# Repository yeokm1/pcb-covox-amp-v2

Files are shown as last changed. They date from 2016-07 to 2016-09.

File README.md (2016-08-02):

# pcb-covox-amp-v2
A tiny sound card based on the Covox Speech Thing design which includes an LM386 amplifier and FT245RL chip to receive data via USB. This project is a combination of my 2 earlier projects [pcb-covox-amp](https://github.com/yeokm1/pcb-covox-amp) and [pcb-usb-ft245r-parallel-adapter](https://github.com/yeokm1/pcb-usb-ft245r-parallel-adapter)

##PCB Design software and addons used

1. Kicad 4.0.2 or later

##Images
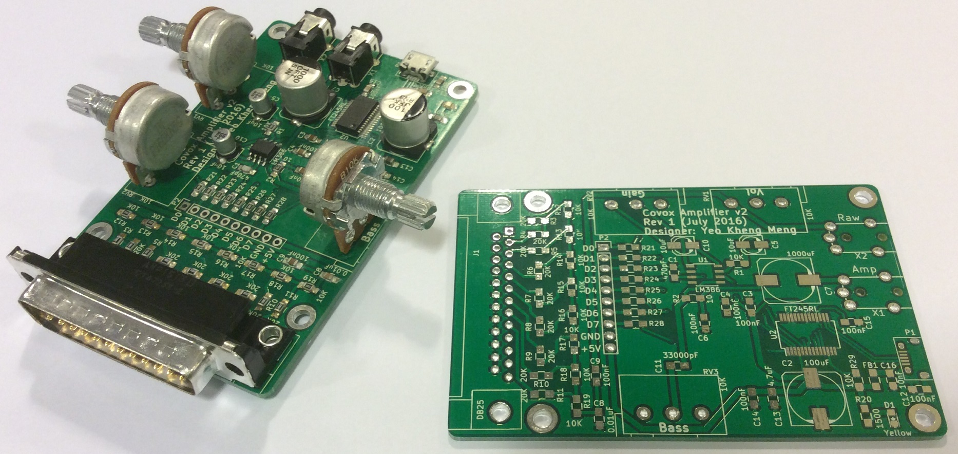
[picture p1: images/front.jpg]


##Schematic drawings

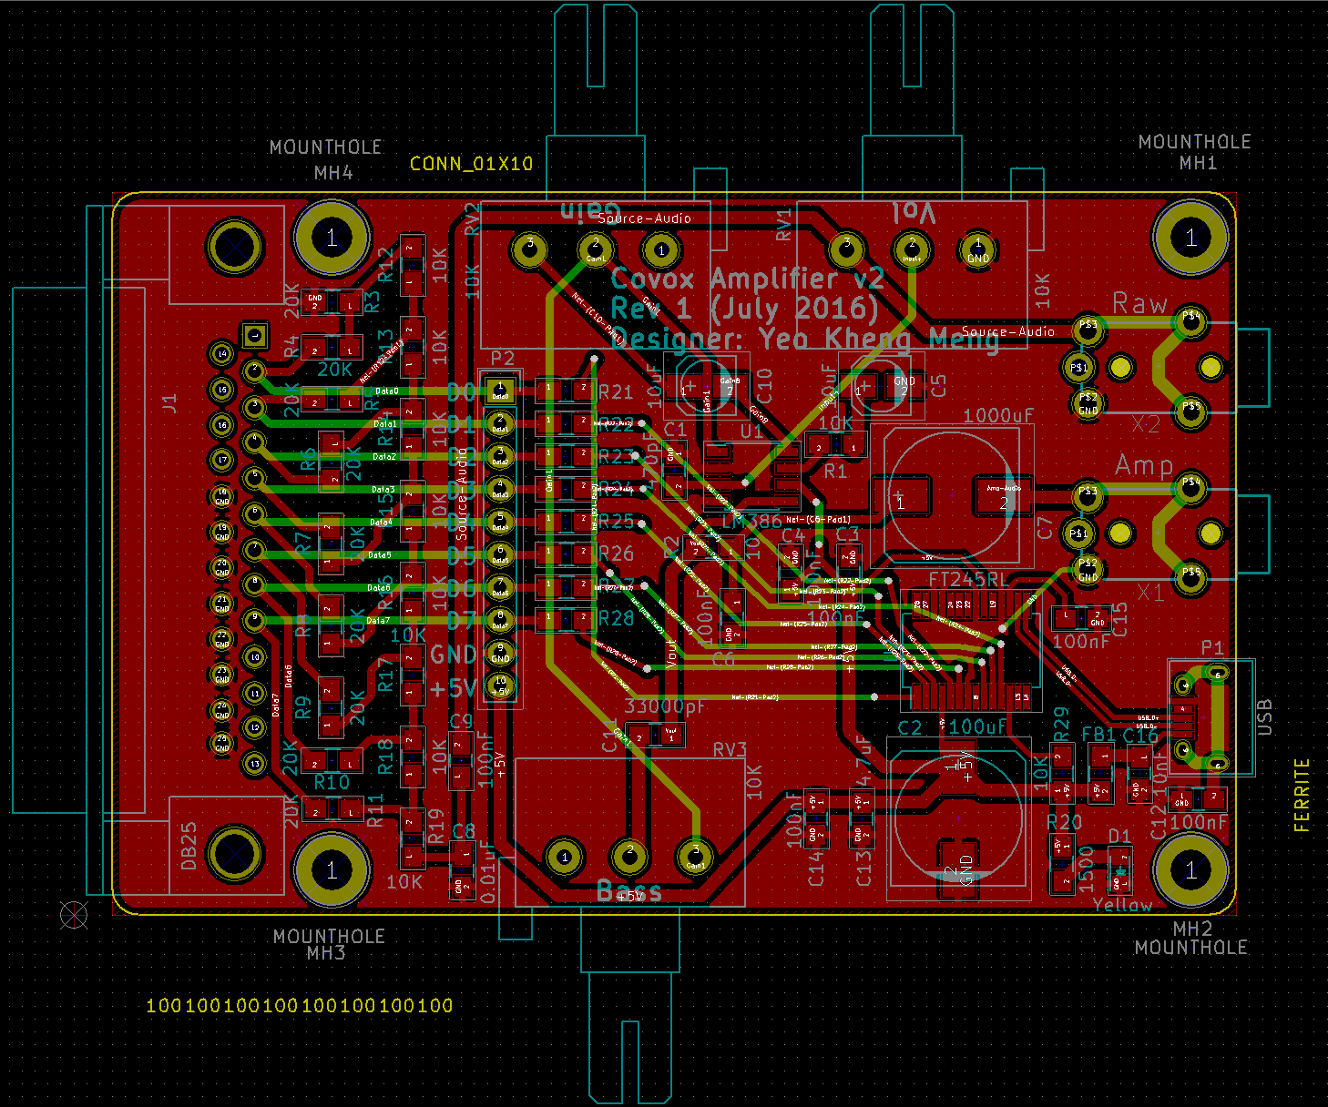
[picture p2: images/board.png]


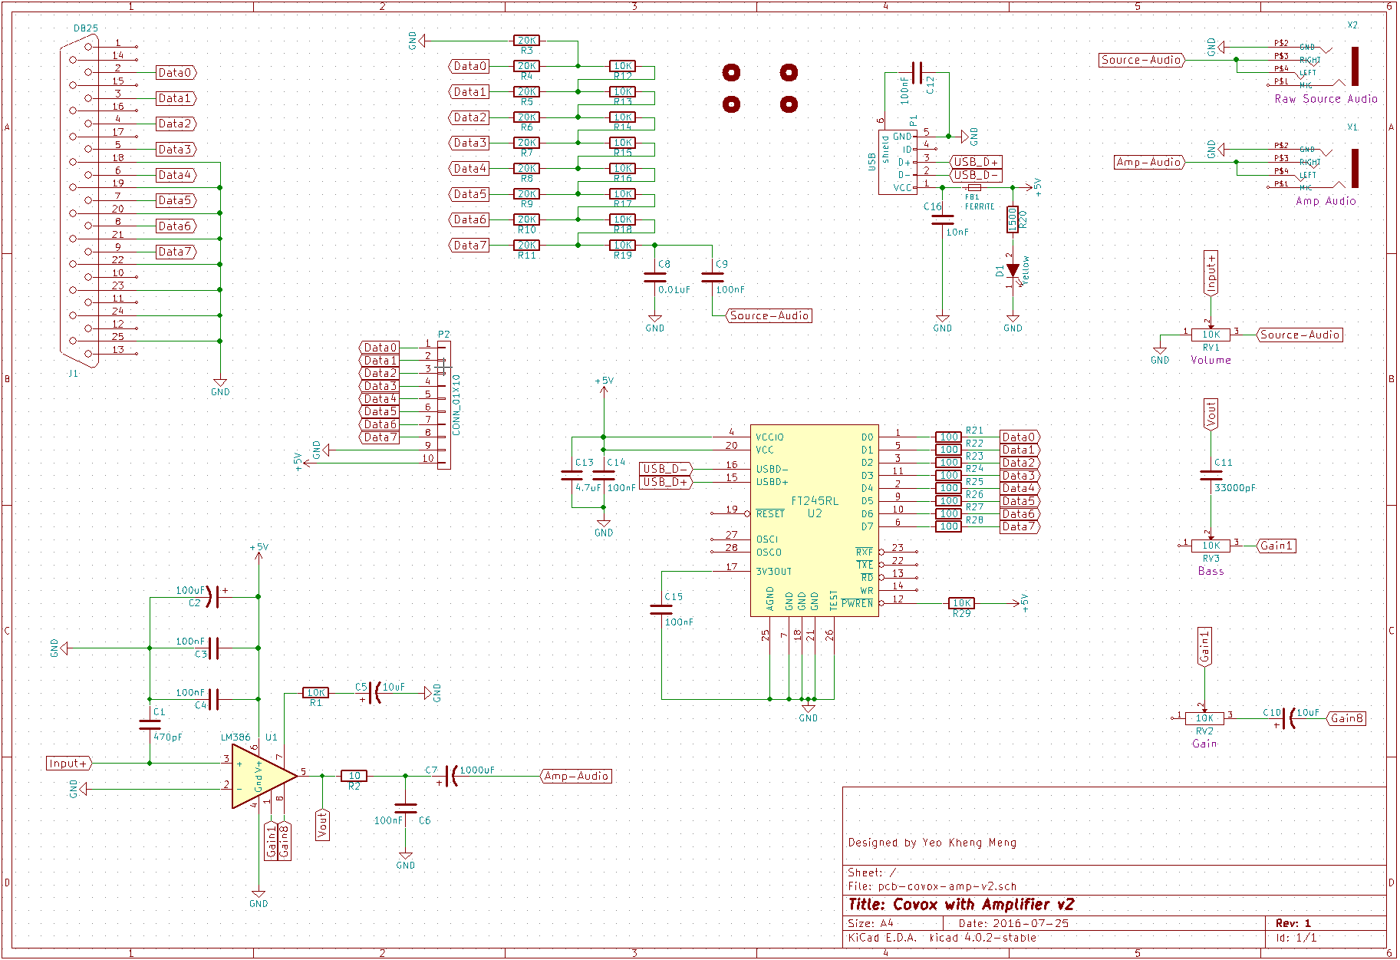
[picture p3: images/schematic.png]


##Parts required
Use Libreoffice to open [pcb-covox-amp-v2-bom.ods](pcb-covox-amp-v2-bom.ods)

##References
1. [Hardware implementation references](https://blog.frantovo.cz/c/307/DAC%20%28zvukov%C3%A1%20karta%29%20pro%20LPT%20port%20a.k.a.%20Covox)
2. [Design reference](http://kb.gr8bit.ru/KB0010/GR8BIT-KB0010-Adding-multimedia-capability-covox-device.html)
3. [MJ-2135 package referenced from coqui-dip](https://github.com/open-eie/coqui-dip)
4. [Amplifier circuit](http://www.circuitbasics.com/build-a-great-sounding-audio-amplifier-with-bass-boost-from-the-lm386/)

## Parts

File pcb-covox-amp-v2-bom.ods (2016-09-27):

Designator | Device | Package | Value | Manufacturer | Part Number | Quantity | Unit Cost | Total Unit Cost | Source webpage
U2 | FTDI FT245RL Interface Bridges, USB to FIFO, 1.8 V, 5.25 V, SSOP, 28 Pins, -40 °C | SSOP28, 5.3mm x 10.2mm | FT245RL | FTDI | FT245RL | 1 | 5.96 | 5.96 | http://sg.element14.com/ftdi/ft245rl/interface-usb-to-fifo-28ssop/dp/1146034
J1 | Standard D Sub Connector, AMPLIMITE HD-20 Series, DB, Plug, 25 Contacts, Steel Body, Through Hole | DB25MC | DB25 | TE Connectivity/ AMP | 5747238-2 | 1 | 5.15 | 5.15 | http://sg.element14.com/te-connectivity-amp/5747238-2/d-sub-connector-plug-25pos/dp/2452364
C1 | SMD Multilayer Ceramic Capacitor | C_0805_HandSoldering | 470pF | AVX | 08055A471JAT2A | 1 | 0.162 | 0.162 | http://sg.element14.com/avx/08055a471jat2a/cap-mlcc-c0g-np0-470pf-50v-0805/dp/1612188
C2 | SMD Aluminium Electrolytic Capacitor, AEC-Q200 FT Series | c_elec_10x10.5 | 100uF, 63V | Panasonic Electronic Components | EEEFK1J101P | 1 | 1.49 | 1.49 | http://sg.element14.com/panasonic-electronic-components/eeefk1j101p/cap-alu-elec-100uf-63v-smd/dp/9696040
C3,C4,C6,C9,C12,C14,C15 | SMD Multilayer Ceramic Capacitor, MCU Series | C_0805_HandSoldering | 100nF | Multicomp | MCU0805F104ZCT | 7 | 0.008 | 0.056 | http://sg.element14.com/multicomp/mcu0805f104zct/cap-mlcc-y5v-100nf-50v-0805/dp/9406409RL
C7 | SMD Aluminium Electrolytic Capacitor, AEC-Q200 FT Series | c_elec_10x10.5 | 1000uF, 16V | Panasonic Electronic Components | EEEFT1C102AP | 1 | 1.47 | 1.47 | http://sg.element14.com/panasonic-electronic-components/eeeft1c102ap/cap-alu-elec-1000uf-16v-smd/dp/2065974
C8 | SMD Multilayer Ceramic Capacitor | C_0805_HandSoldering | 0.01uF | AVX | 08055C103KAT2A | 1 | 0.049 | 0.049 | http://sg.element14.com/avx/08055c103kat2a/cap-mlcc-x7r-10nf-50v-0805/dp/499225
C11 | SMD Multilayer Ceramic Capacitor | C_0805_HandSoldering | 33000pF | AVX | 08051C333KAT2A | 1 | 0.076 | 0.076 | http://sg.element14.com/avx/08051c333kat2a/cap-mlcc-x7r-33nf-100v-0805/dp/1833886
P1 | USB Connector, Micro USB Type B, USB 2.0, Receptacle, 5 Ways, Surface Mount, Through Hole Mount | USB_Micro-B | Micro-USB | Hirose | ZX62D-B-5PA8(30) | 1 | 1.09 | 1.09 | http://sg.element14.com/webapp/wcs/stores/servlet/ProductDisplay?productId=141569308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
R1,R12,R13,R14,R15,R16,R17,R18,R19,R29 | Surface Mount Chip Resistor, Thick Film, AEC-Q200 ERJ6E Series | R_0805_HandSoldering | 10K, ±0.5% | Panasonic Electronic Components | ERJ6RBD1002V | 10 | 0.047 | 0.47 | http://sg.element14.com/panasonic-electronic-components/erj6rbd1002v/res-thick-film-10k-0-5-0-1w-0805/dp/2380289
R2 | Thick Film Resistor | R_0805_HandSoldering | 10 | Panasonic Electronic Components | ERJ-6ENF10R0V | 1 | 0.156 | 0.156 | http://sg.element14.com/panasonic-electronic-components/erj-6enf10r0v/sistor-thick-film-10-ohm-125mw/dp/2284223
R3,R4,R5,R6,R7,R8,R9,R10,R11 | Surface Mount Chip Resistor, Thick Film, AEC-Q200 ERJ6E Series | R_0805_HandSoldering | 20K, ±0.5% | Panasonic Electronic Components | ERJ6RBD2002V | 9 | 0.047 | 0.423 | http://sg.element14.com/panasonic-electronic-components/erj6rbd2002v/res-thick-film-20k-0-5-0-1w-0805/dp/2380338
RV1,RV2,RV3 | Rotary Potentiometer | Potentiometer_Alps-RK163-single_15mm | 10K | BI Technologies/ TT Electronics | 16mm | 3 | 1.16 | 3.48 | http://sg.element14.com/bi-technologies-tt-electronics/p160kn-0qd15b10k/rotary-potentiometer-10kohm-16mm/dp/1782728
U1 | LM386M-1 Audio Power Amplifier, AB, 1 Channel, 325 mW, 4V to 12V | SOIC8 | LM386 | Texas Instruments | LM386M-1/NOPB | 1 | 1.48 | 1.48 | http://sg.element14.com/texas-instruments/lm386m-1-nopb/amp-power-audio-mono-class-ab/dp/1564701
D1 | LED, Yellow Green, SMD, 1.25mm x 1.4mm, 20 mA, 2 V, 575 nm | LED_0805 | Yellow, Green | Dialight | 5988160107F | 1 | 0.657 | 0.657 | http://sg.element14.com/dialight/5988160107f/led-0805-yellow-green-40mcd/dp/1465994
R20 | Thick Film Resistor | R_0805_HandSoldering | 1500 | Multicomp | MC0805S8F1501T5E | 1 | 0.005 | 0.005 | http://sg.element14.com/multicomp/mc0805s8f1501t5e/res-thick-film-1k5-1-0-125w-0805/dp/1632464
X1, X2 | Phone Audio Connector, Socket, 3.5 mm, 4 Contacts, PCB Mount | mj-2135-MJ-2135 | TRRS | Pro Signal | MJ-2135 | 2 | 3.79 | 7.58 | http://sg.element14.com/pro-signal/mj-2135/connector-rca-jack-3-5mm-tht-4way/dp/1267377
C5,C10 | SMD Aluminium Electrolytic Capacitor, AEC-Q200 FT Series | c_elec_4x5.3 | 10uF, 10V | Panasonic Electronic Components | EEE1AA100NR | 2 | 0.99 | 1.98 | http://sg.element14.com/panasonic-electronic-components/eee1aa100nr/cap-alu-elec-10uf-10v-smd/dp/2326096
C13 | SMD Multilayer Ceramic Capacitor | C_0805_HandSoldering | 4.7uF | Kemet | C0805C475K3PACTU | 1 | 0.469 | 0.469 | http://sg.element14.com/kemet/c0805c475k3pactu/cap-mlcc-x5r-4-7uf-25v-0805/dp/1572631
C16 | SMD Multilayer Ceramic Capacitor | C_0805_HandSoldering | 10nF | AVX | 08055C103KAT2A | 1 | 0.049 | 0.049 | http://sg.element14.com/avx/08055c103kat2a/cap-mlcc-x7r-10nf-50v-0805/dp/499225
FB1 | Ferrite Bead | R_0805_HandSoldering | FERRITE | Laird Technologies | MI0805K400R-10 | 1 | 0.103 | 0.103 | http://sg.element14.com/laird-technologies/mi0805k400r-10/ferrite-bead-2012-100mhz-40r/dp/2292459
R21,R22,R23,R24,R25,R26,R27,R28 | Surface Mount Chip Resistor, Thick Film, AEC-Q200 ERJ6E Series | R_0805_HandSoldering | 100 | Panasonic Electronic Components | ERJ6RBD1000V | 8 | 0.047 | 0.376 | https://sg.element14.com/panasonic-electronic-components/erj6rbd1000v/res-thick-film-100r-0-5-0-1w-0805/dp/2380287
- | PCB (Hasl lead free) | 5x10cm x 2 layer | - | Elecrow | - | 1 | 8 | 8 | http://www.elecrow.com/5pcs-2-layer-pcb-p-1174.html
 |  |  |  |  |  |  | Subtotal | 40.731
 |  |  |  |  |  |  | GST 7% | 2.85117
 |  |  |  |  |  |  | Total (SGD) | 43.58217

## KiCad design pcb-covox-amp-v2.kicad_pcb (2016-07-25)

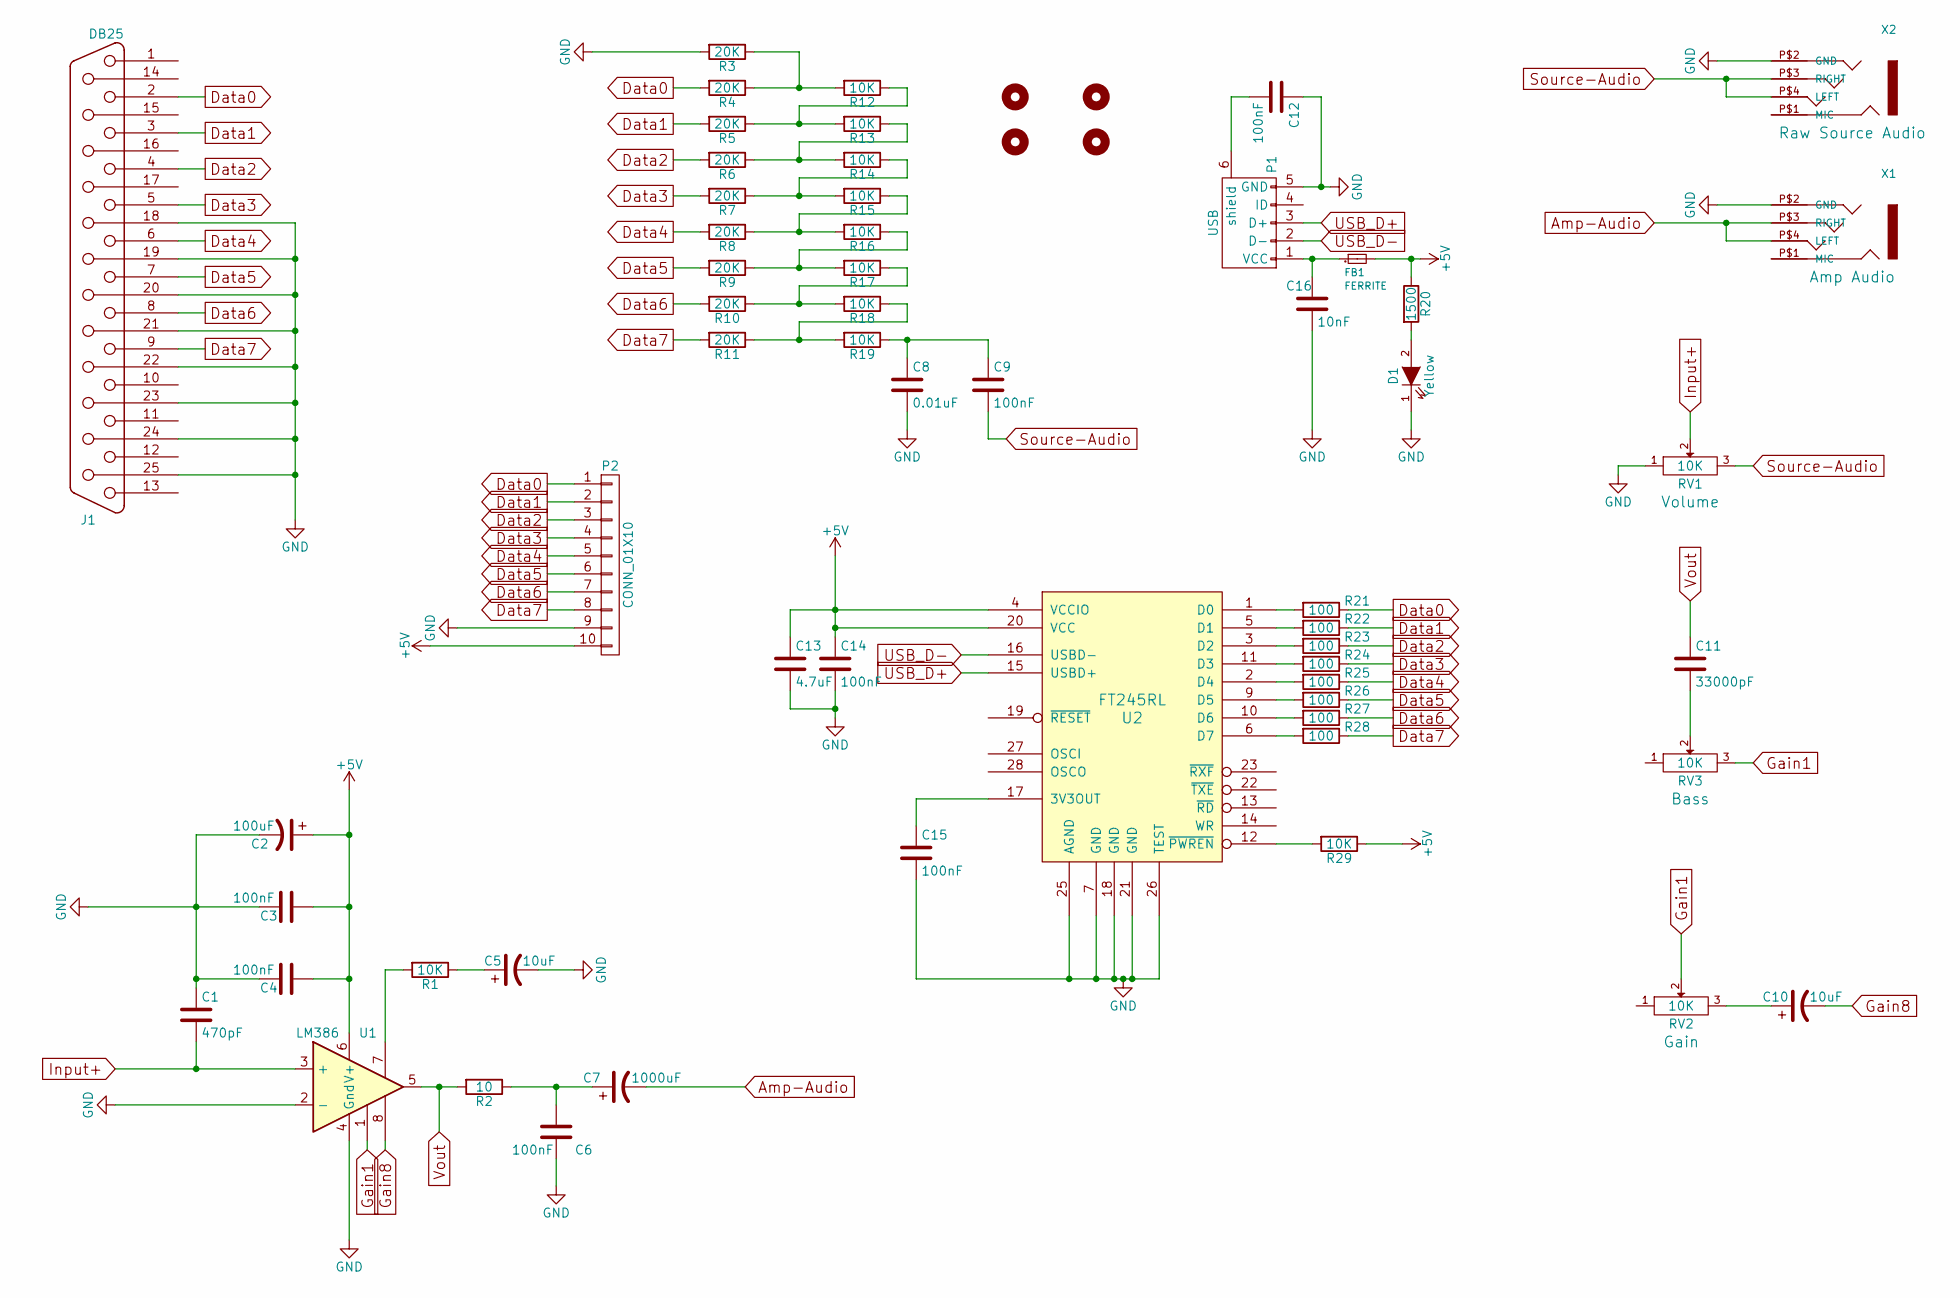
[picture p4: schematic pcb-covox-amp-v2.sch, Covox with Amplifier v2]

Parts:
C1: 470pF; C_0805_HandSoldering
C2: 100uF; c_elec_10x10.5
C3, C4, C6, C9, C12, C14, C15: 100nF; C_0805_HandSoldering
C5, C10: 10uF; c_elec_4x5.3
C7: 1000uF; c_elec_10x10.5
C8: 0.01uF; C_0805_HandSoldering
C11: 33000pF; C_0805_HandSoldering
C13: 4.7uF; C_0805_HandSoldering
C16: 10nF; C_0805_HandSoldering
D1: Yellow; LED_0805
FB1: FERRITE; R_0805_HandSoldering
J1: DB25; DB25MC
MH1, MH2, MH3, MH4: MOUNTHOLE; MountingHole_3.2mm_M3_ISO14580_Pad
P1: USB; USB_Micro-B
P2: CONN_01X10; Pin_Header_Straight_1x10
R1, R12, R13, R14, R15, R16, R17, R18, R19, R29: 10K; R_0805_HandSoldering
R2: 10; R_0805_HandSoldering
R3, R4, R5, R6, R7, R8, R9, R10, R11: 20K; R_0805_HandSoldering
R20: 1500; R_0805_HandSoldering
R21, R22, R23, R24, R25, R26, R27, R28: 100; R_0805_HandSoldering
RV1, RV2, RV3: 10K; Potentiometer_Alps-RK163-single_15mm
U1: LM386; SOIC-8_3.9x4.9mm_Pitch1.27mm
U2: FT245RL; SSOP-28_5.3x10.2mm_Pitch0.65mm
X1: Amp; mj-2135-MJ-2135
X2: Raw; mj-2135-MJ-2135

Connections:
+5V: C2.1, C3.1, C4.1, C13.1, C14.1, FB1.2, P2.10, R20.1, R29.1, U1.6 (V+), U2.4 (VCCIO), U2.20 (VCC)
Amp-Audio: C7.2, X1.P$3 (RIGHT), X1.P$4 (LEFT), X1.P$5 (LEFT)
Data0: J1.2, P2.1, R4.2, R21.1
Data1: J1.3, P2.2, R5.2, R22.1
Data2: J1.4, P2.3, R6.2, R23.1
Data3: J1.5, P2.4, R7.2, R24.1
Data4: J1.6, P2.5, R8.2, R25.1
Data5: J1.7, P2.6, R9.2, R26.1
Data6: J1.8, P2.7, R10.2, R27.1
Data7: J1.9, P2.8, R11.2, R28.1
GND: C1.1, C2.2, C3.2, C4.2, C5.2, C6.2, C8.2, C12.1, C13.2, C14.2, C15.2, C16.2, D1.1 (K), J1.18, J1.19, J1.20, J1.21, J1.22, J1.23, J1.24, J1.25, P1.5 (GND), P2.9, R3.2, RV1.1, U1.2 (-), U1.4 (Gnd), U2.7 (GND), U2.18 (GND), U2.21 (GND), U2.25 (AGND), U2.26 (TEST), X1.P$2 (GND), X2.P$2 (GND)
Gain1: RV2.2, RV3.3, U1.1
Gain8: C10.2, U1.8
Input+: C1.2, RV1.2, U1.3 (+)
unnamed: C5.1, R1.1
unnamed: C6.1, C7.1, R2.1
unnamed: C8.1, C9.1, R19.1
unnamed: C10.1, RV2.3
unnamed: C11.2, RV3.2
unnamed: C12.2, P1.6 (shield)
unnamed: C15.1, U2.17 (3V3OUT)
unnamed: C16.1, FB1.1, P1.1 (VCC)
unnamed: D1.2 (A), R20.2
unnamed: R1.2, U1.7
unnamed: R10.1, R17.1, R18.2
unnamed: R11.1, R18.1, R19.2
unnamed: R5.1, R12.1, R13.2
unnamed: R3.1, R4.1, R12.2
unnamed: R6.1, R13.1, R14.2
unnamed: R7.1, R14.1, R15.2
unnamed: R8.1, R15.1, R16.2
unnamed: R9.1, R16.1, R17.2
unnamed: R21.2, U2.1 (D0)
unnamed: R22.2, U2.5 (D1)
unnamed: R23.2, U2.3 (D2)
unnamed: R24.2, U2.11 (D3)
unnamed: R25.2, U2.2 (D4)
unnamed: R26.2, U2.9 (D5)
unnamed: R27.2, U2.10 (D6)
unnamed: R28.2, U2.6 (D7)
unnamed: R29.2, U2.12 (~PWREN)
Source-Audio: C9.2, RV1.3, X2.P$3 (RIGHT), X2.P$4 (LEFT), X2.P$5 (LEFT)
USB_D+: P1.3 (D+), U2.15 (USBD+)
USB_D-: P1.2 (D-), U2.16 (USBD-)
Vout: C11.1, R2.2, U1.5

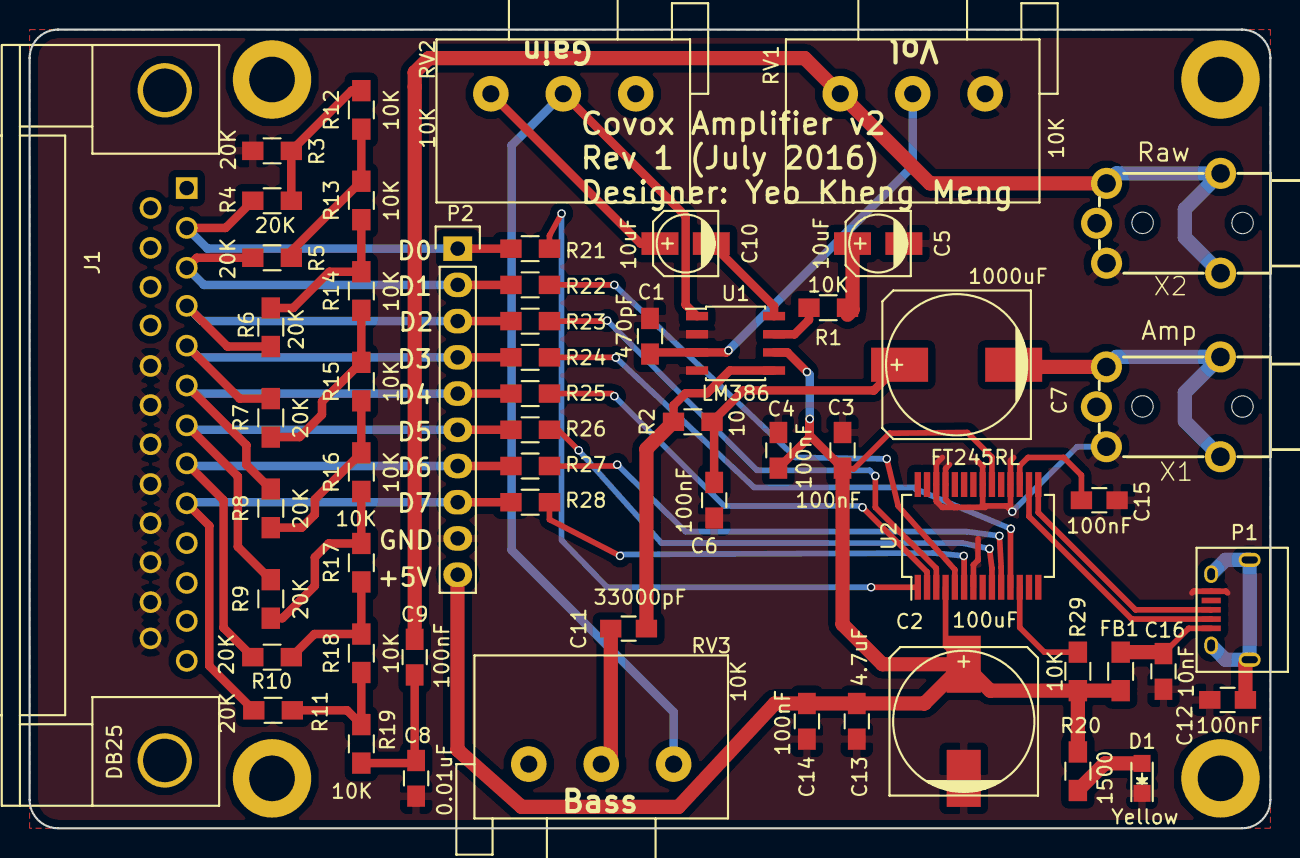
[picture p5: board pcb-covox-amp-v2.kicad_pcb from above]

Board: 2 copper layers, 87.0 x 56.0 mm, 61 parts (0 on the bottom side), 45 nets.

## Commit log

2016-07-24 another commit
    [pcb-covox-amp-v2.kicad_pcb, pcb-covox-amp-v2.sch]
2016-07-25 updated gerber
    [pcb-covox-amp-v2.kicad_pcb]
2016-08-02 board image
2016-08-02 updated bom
    [pcb-covox-amp-v2-bom.ods]
2016-09-27 update bom column name to value
    [pcb-covox-amp-v2-bom.ods]
